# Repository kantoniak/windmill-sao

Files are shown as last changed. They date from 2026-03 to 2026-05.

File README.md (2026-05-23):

# Windmill SAO

> [!IMPORTANT]
> ### **Hackaday Europe 2026** and **Open Hardware Summit 2026** folks:
> Please use `README.md` from the [`rev1-rc2-wip` branch](https://github.com/kantoniak/windmill-sao/tree/kantoniak/rev1-rc2-wip).

Dutch [tower mill](https://en.wikipedia.org/wiki/Tower_mill) in a [SAO (Simple Add-on/Shitty Add-on)](https://hackaday.io/project/52950-shitty-add-ons/log/159806-introducing-the-shitty-add-on-v169bis-standard) form factor.

The project consists of:
* 3D printed enclosure (see [enclosure/](./enclosure/))
* PCB design (see [hardware/](./hardware/))
* PCB firmware (see [firmware/](./firmware/))

Some components are available in the repository only as scripts that generate resources. See the releases for generated outputs.

## Enclosure

Enclosure is built from a headless Python script that generates a FreeCAD model. Use FreeCAD 1.0 stable.

<p align="center">
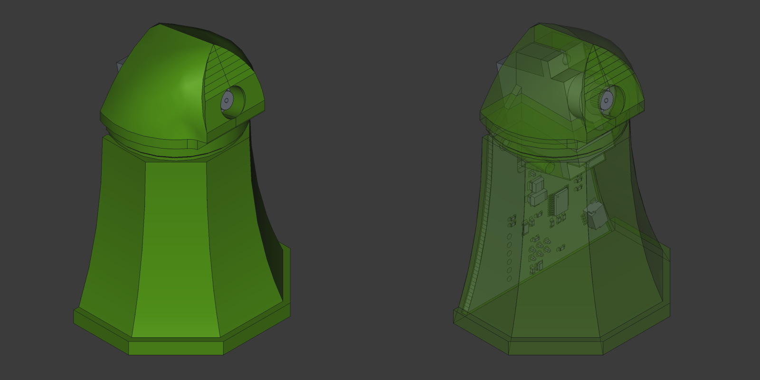
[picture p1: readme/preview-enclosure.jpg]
Previews of Windmill SAO enclosure
  
</p>

### Windows

1. Add FreeCAD's `bin/` directory to `PATH`. Usually `C:\Program Files\FreeCAD 1.0\bin\`
2. Generate the model:

    ```powershell
    cd enclosure/
    freecadcmd model.py
    ```

### Linux

1. Install FreeCAD:

    ```bash
    # Install FreeCAD
    sudo add-apt-repository ppa:freecad-maintainers/freecad-stable
    sudo apt update
    sudo apt install freecad
    ```
2. Generate the model:

    ```powershell
    cd enclosure/
    freecadcmd model.py
    ```

## PCB

The PCB was designed in KiCad. See `hardware/` for the source files and releases for generated outputs.

<p align="center">
  <a href="readme/preview-pcb.png">
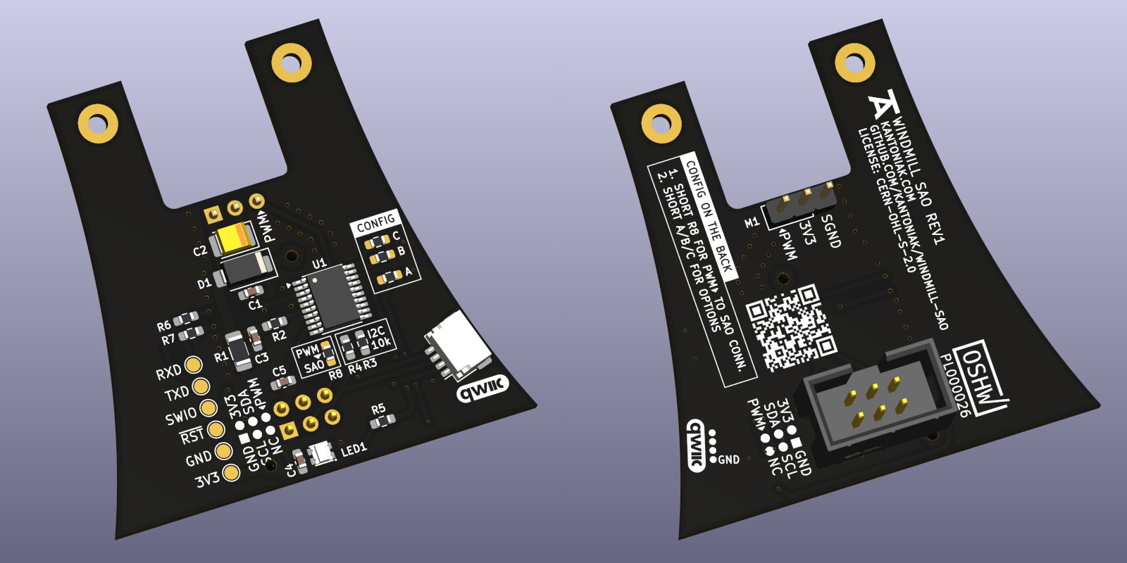
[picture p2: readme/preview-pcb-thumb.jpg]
Previews of Windmill SAO PCB
    
  </a>
</p>

## Firmware

The PCB is built around CH32V003 and the firmware uses open-source [ch32fun](https://github.com/cnlohr/ch32fun) stack. Use PlatformIO to program the chip.

## License

[Open source hardware project: `[OSHW] PL000026`<br />
OSHW UID: PL000026
](https://certification.oshwa.org/pl000026.html)

This project in its entirety is licensed under the `CERN-OHL-S-2.0` license - see the [LICENSE](LICENSE) file for details.

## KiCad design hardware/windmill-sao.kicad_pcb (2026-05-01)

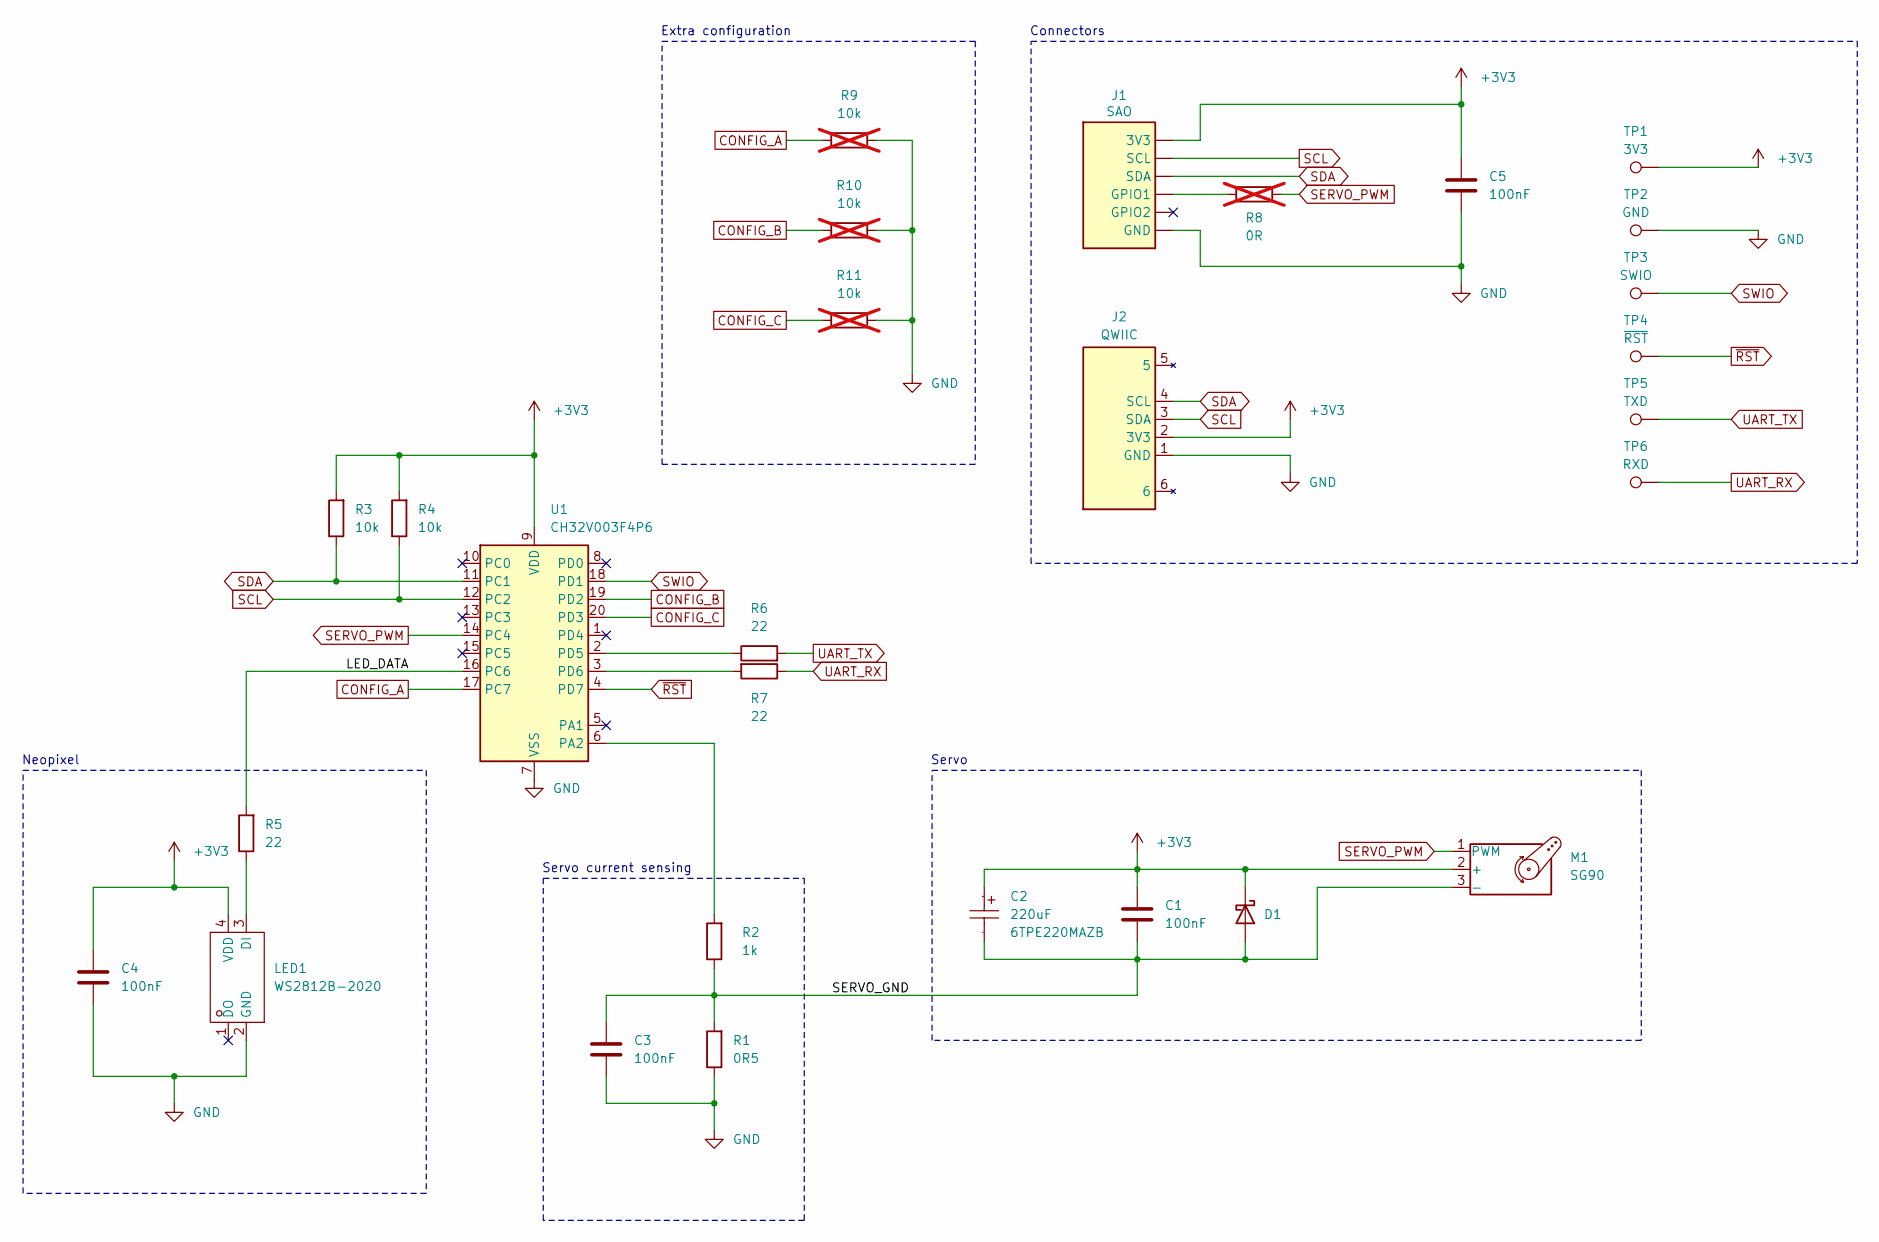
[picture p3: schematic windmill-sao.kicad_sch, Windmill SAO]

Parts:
C1, C3, C4, C5: 100nF; C_0603_1608Metric_Pad1.08x0.95mm_HandSolder; LCSC Part # C14663
C2: 220uF; CP_EIA-3528-21_Kemet-B_HandSolder; Manufacturer Part 6TPE220MAZB; LCSC Part Name 220uF ±20% 6.3V MSL=3拆包后请尽快使用
D1: D_Schottky; D_SMA; LCSC Part # C2480
J1: SAO; SAO_Header_Addon_Side
J2: QWIIC; JST_SH_SM04B-SRSS-TB_1x04-1MP_P1.00mm_Horizontal; Manufacturer Part SM04B-SRSS-TB(LF)(SN); LCSC Part # C160404
LED1: LED-SMD_4P-L2.0-W2.0-TL_WS2812B-2020; Manufacturer Part WS2812B-2020; JLCPCB Part # C965555
M1: SG90; PinHeader_1x03_P2.54mm_Vertical_SG90
R1: 0R5; R_1206_3216Metric_Pad1.30x1.75mm_HandSolder; LCSC Part # C25340
R2: 1k; R_0603_1608Metric_Pad0.98x0.95mm_HandSolder; LCSC Part # C21190
R3, R4: 10k; R_0603_1608Metric_Pad0.98x0.95mm_HandSolder; LCSC Part # C25804
R5, R6, R7: 22; R_0603_1608Metric_Pad0.98x0.95mm_HandSolder; LCSC Part # C23345
R8: 0R; R_0603_1608Metric_Pad0.98x0.95mm_HandSolder; not fitted
R9, R10, R11: 10k; R_0603_1608Metric_Pad0.98x0.95mm_HandSolder; not fitted
TP1: 3V3; TestPoint_Pad_D1.5mm
TP2: GND; TestPoint_Pad_D1.5mm
TP3: SWIO; TestPoint_Pad_D1.5mm
TP4: ~{RST}; TestPoint_Pad_D1.5mm
TP5: TXD; TestPoint_Pad_D1.5mm
TP6: RXD; TestPoint_Pad_D1.5mm
U1: CH32V003F4P6; TSSOP-20_4.4x6.5mm_P0.65mm; LCSC Part # C5187096

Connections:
+3V3: C1.1, C2.1, C4.1, C5.1, D1.1 (K), J1.6 (3V3), J2.2 (3V3), LED1.4 (VDD), M1.2 (+), R3.2, R4.2, TP1.1 (1_1), U1.9 (VDD)
/LED_DATA: R5.2, U1.16 (PC6)
/SERVO_GND: C1.2, C2.2, C3.1, D1.2 (A), M1.3 (-), R1.2, R2.1
CONFIG_A: R9.1, U1.17 (PC7)
CONFIG_B: R10.2, U1.19 (PD2)
CONFIG_C: R11.2, U1.20 (PD3)
GND: C3.2, C4.2, C5.2, J1.1 (GND), J2.1 (GND), LED1.2 (GND), R1.1, R9.2, R10.1, R11.1, TP2.1 (1_1), U1.7 (VSS)
unnamed: J1.4 (GPIO1), R8.1
unnamed: LED1.3 (DI), R5.1
unnamed: R2.2, U1.6 (PA2)
unnamed: R6.1, U1.2 (PD5)
unnamed: R7.2, U1.3 (PD6)
SCL: J1.2 (SCL), J2.3 (SDA), R4.1, U1.12 (PC2)
SDA: J1.5 (SDA), J2.4 (SCL), R3.1, U1.11 (PC1)
SERVO_PWM: M1.1 (PWM), R8.2, U1.14 (PC4)
SWIO: TP3.1 (1_1), U1.18 (PD1)
UART_RX: R7.1, TP6.1 (1_1)
UART_TX: R6.2, TP5.1 (1_1)
~RST: TP4.1 (1_1), U1.4 (PD7)

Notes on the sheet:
Extra configuration
Servo current sensing
Connectors
Neopixel
Servo

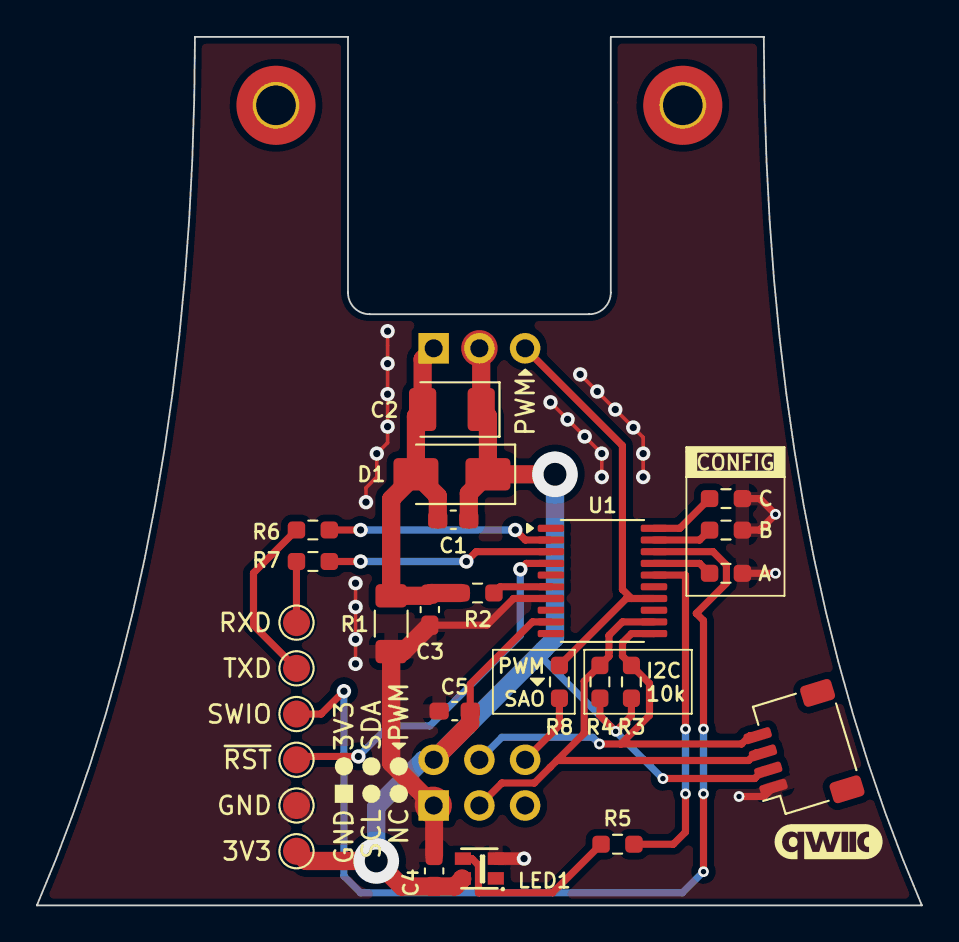
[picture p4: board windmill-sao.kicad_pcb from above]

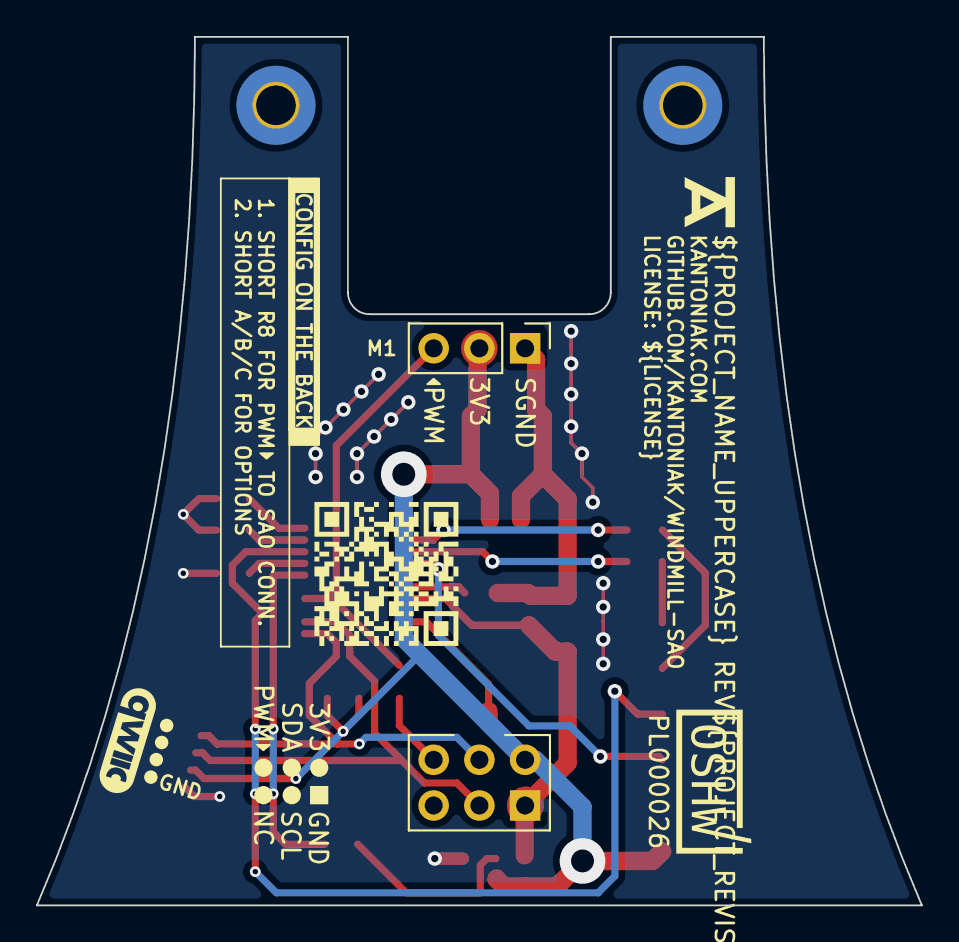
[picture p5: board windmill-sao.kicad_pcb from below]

Board: 2 copper layers, 49.2 x 48.2 mm, 32 parts (3 on the bottom side), 19 nets.

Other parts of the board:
MountingHole1, MountingHole2: MountingHole_2.2mm_M2_Pad_TopBottom
QWIIC_Back: QWIIC_Back; qwiic_logo
QWIIC_Front: QWIIC_Front; qwiic_logo

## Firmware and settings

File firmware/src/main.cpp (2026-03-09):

#include "ch32fun.h"
#include <stdio.h>

#define PIN_LED PC1

int main()
{
  SystemInit();
  Delay_Ms(100);

  // Enable GPIO C and TIM1
  RCC->APB2PCENR |= RCC_APB2Periph_GPIOC | RCC_APB2Periph_TIM1;

  // Set PC4 to alternate function output for TIM1_CH4
  funPinMode(PC4, GPIO_Speed_10MHz | GPIO_CNF_OUT_PP_AF);

  // Reset TIM1
  RCC->APB2PRSTR |= RCC_APB2Periph_TIM1;
  RCC->APB2PRSTR &= ~RCC_APB2Periph_TIM1;

  // Set values, enable preload, emit change event
  // TODO: Review how to compute these values for different frequencies and duty cycles.
  TIM1->PSC = 0;
  TIM1->ATRLR = 2048 - 1;
  TIM1->CTLR1 = TIM_ARPE;
  TIM1->SWEVGR |= TIM_UG;

  // Enable TIM1_CH4
  TIM1->CCER |= TIM_CC4E | TIM_CC4P; // Active low
  TIM1->CHCTLR2 |= TIM_OC4M_2 | TIM_OC4M_1 | TIM_OC4PE;

  TIM1->CH4CVR = 0;
  TIM1->BDTR |= TIM_MOE;
  TIM1->CTLR1 |= TIM_CEN;

  // We're moving within [1, arr-1] to avoid the weird behavior of 0 and arr.
  uint32_t arr = (TIM1->ATRLR + 1) / 8;
  uint32_t count = 1;
  bool up = true;
  while(true) {
    TIM1->CH4CVR = count;
    if (up) {
      if (++count >= (arr-1)) up = false;
    } else {
      if (count-- <= 1) up = true;
    }
    Delay_Ms(5);
  }
}

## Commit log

2025-12-29 Add bushing to the SG90 model
2025-12-31 Fix servo position around origin
2026-01-10 Cut tower's back side
2026-01-10 Build PCB object
2026-01-10 Move enclosure-specific ignores to enclosure/
2026-01-10 Export PCB outline as DXF from FreeCAD script
2026-01-10 Set up Kicad project
    [windmill-sao.kicad_pcb, windmill-sao.kicad_sch]
2026-01-18 Create servo tunnel
2026-01-18 Add STL export
2026-01-18 Move cap loft to vertical center between base and bearing
2026-02-22 Build cap front assembly with shingles
2026-03-09 Convert blink sketch to fade in/out using PWM timer
2026-04-09 Cut away a support shape for 3D printing
2026-04-11 Add mounting holes to PCB outline
2026-04-11 Add heat insert holes in the tower
2026-04-11 Import board outline into Edge.Cuts and add M2 pads
    [windmill-sao.kicad_pcb]
2026-04-11 Import STEP file with PCB
2026-04-13 Add space-sensitive components to the PCB
    [windmill-sao.kicad_pcb, windmill-sao.kicad_sch]
2026-04-13 Add main PCB components
    [windmill-sao.kicad_pcb, windmill-sao.kicad_sch]
2026-04-21 Add passives to the schematic, PCB WIP
    [windmill-sao.kicad_pcb, windmill-sao.kicad_sch]
2026-04-26 Add configuration resistors, route the PCB
    [windmill-sao.kicad_pcb, windmill-sao.kicad_sch]
2026-04-26 Add QWIIC logo and supplier part numbers
    [windmill-sao.kicad_pcb, windmill-sao.kicad_sch]
2026-04-26 Clean up PCB
    * Add GND fill on front layer and via stitching
    * Use smaller text size for designators
    * Place info silkscreen and QR code
    * Add 3D model for SAO connector
    [windmill-sao.kicad_pcb]
2026-04-27 Add C5 and clean up silkscreen even more
    [windmill-sao.kicad_pcb, windmill-sao.kicad_sch]
2026-04-27 Add LICENSE and project metadata
    [windmill-sao.kicad_pcb]
2026-04-27 Fix thermal release violations
    [windmill-sao.kicad_pcb]
2026-05-01 Add OSHWA cert no. to silkscreen
    [windmill-sao.kicad_pcb]
2026-05-11 Update PCB preview

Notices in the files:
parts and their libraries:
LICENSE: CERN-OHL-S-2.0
